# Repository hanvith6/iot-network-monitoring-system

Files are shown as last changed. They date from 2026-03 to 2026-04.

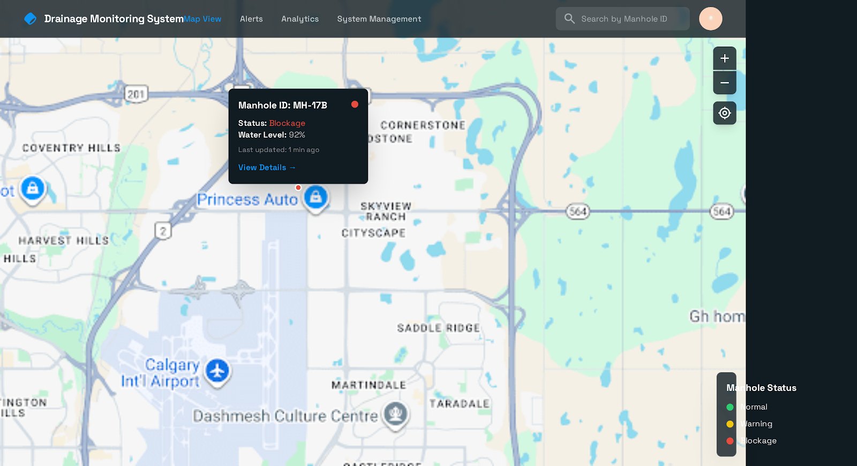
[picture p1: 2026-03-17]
docs/images/image copy 2.png

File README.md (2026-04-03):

# Real-Time Drainage Monitoring System

> **Final Year Project** — Real-time underground drainage monitoring using ESP32 microcontrollers, MQTT, ThingsBoard cloud, and a custom Next.js dashboard.

---

## Overview

This project implements an end-to-end IoT system for monitoring urban drainage infrastructure in real time. ESP32 edge nodes equipped with ultrasonic depth sensors and flow-rate meters continuously measure water levels inside drainage pipes. Readings are transmitted over WiFi via the MQTT protocol to a cloud broker, ingested by ThingsBoard for persistence and alerting, and visualised through a purpose-built web dashboard built with Next.js.

The system autonomously classifies pipe conditions across four severity levels — **Normal → Early Sedimentation → Partial Block → Overflow Risk** — and raises configurable alarms before a blockage becomes critical.

---

## System Architecture

```
┌─────────────────────────────────────────────────────────────┐
│                       EDGE LAYER                            │
│   ESP32 + HC-SR04 (Ultrasonic) + YF-S201 (Flow Sensor)     │
│   Multi-level state detection · Time-to-Overflow ETA        │
└──────────────────────────┬──────────────────────────────────┘
                           │ WiFi (802.11 b/g/n)
                           ▼
┌─────────────────────────────────────────────────────────────┐
│                     TRANSPORT LAYER                         │
│         MQTT Broker (Mosquitto / ThingsBoard MQTT)          │
│    Topic: v1/devices/me/telemetry  ·  Port 1883             │
└──────────────────────────┬──────────────────────────────────┘
                           │ JSON Telemetry Payload
                           ▼
┌─────────────────────────────────────────────────────────────┐
│                      CLOUD LAYER                            │
│    ThingsBoard (Device Management · Alarm Rules · API)      │
│    REST API / WebSocket for dashboard data feed             │
└──────────────────────────┬──────────────────────────────────┘
                           │ WebSocket / MQTT over WSS
                           ▼
┌─────────────────────────────────────────────────────────────┐
│                  VISUALISATION LAYER                        │
│     Next.js 16 Dashboard — Live charts, alarms, status      │
└─────────────────────────────────────────────────────────────┘
```

---

## Technologies Used

| Layer | Technology |
|---|---|
| Microcontroller | ESP32 (Espressif) |
| Sensors | HC-SR04 Ultrasonic, YF-S201 Flow Meter |
| Communication | MQTT (PubSubClient library) |
| MQTT Broker | Mosquitto (local) / ThingsBoard Cloud |
| Cloud Platform | ThingsBoard CE |
| Frontend | Next.js 16, React 19, Recharts, Tailwind CSS |
| Language | C++ (Firmware), TypeScript (Dashboard) |

---

## Repository Structure

```
iot-network-monitoring-system/
│
├── firmware/                         # ESP32 Arduino firmware
│   ├── esp32_firmware.ino            # Primary firmware (ThingsBoard MQTT)
│   ├── esp32_firmware_mosquitto.ino  # Variant for public Mosquitto broker
│   ├── esp32_firmware_blynk.ino      # Prototype variant (Blynk platform)
│   ├── PubSubClient.cpp              # MQTT client library
│   └── PubSubClient.h
│
├── dashboard/                        # Next.js web dashboard
│   ├── app/                          # App router pages
│   ├── components/                   # UI components
│   ├── hooks/use-system-data.ts      # MQTT data hook (live + simulation)
│   ├── lib/types.ts                  # Shared TypeScript types
│   └── package.json
│
├── thingsboard/
│   └── dashboards/                   # Exported ThingsBoard dashboard JSON files
│       ├── thingsboard_dashboard_final.json
│       ├── thingsboard_dashboard_v4.json
│       ├── thingsboard_dashboard_v2.json
│       └── thingsboard_dashboard.json
│
├── docs/                             # Project documentation
│   ├── architecture.md               # System design & data flow
│   ├── setup.md                      # Full setup & deployment guide
│   ├── alarm_setup.md                # ThingsBoard alarm configuration guide
│   └── images/                       # Architecture diagrams & screenshots
│
├── research/
│   └── IEEE_paper.docx               # Supporting IEEE research paper
│
├── .gitignore
└── README.md
```

---

## Documentation

### Guides

| Document | Description |
|---|---|
| [docs/setup.md](docs/setup.md) | **Full setup guide** — hardware wiring, firmware flashing, MQTT broker, ThingsBoard, and dashboard deployment |
| [docs/architecture.md](docs/architecture.md) | **System architecture** — layer-by-layer design, MQTT message flow, state machine, and data pipeline |
| [docs/alarm_setup.md](docs/alarm_setup.md) | **Alarm configuration** — step-by-step ThingsBoard Device Profile alarm rules |

### ThingsBoard Dashboards

All dashboard iterations are exported as importable JSON files in [`thingsboard/dashboards/`](thingsboard/dashboards/):

| File | Description |
|---|---|
| `thingsboard_dashboard_final.json` | **Latest production dashboard** (use this one) |
| `thingsboard_dashboard_v4.json` | Iteration 4 — refined layout |
| `thingsboard_dashboard_v2.json` | Iteration 2 — initial charts |
| `thingsboard_dashboard.json` | Original prototype |

### Research

> **IEEE paper currently under peer review — not yet published.**  
> The supporting research paper is available upon request. Contact via GitHub profile.  

---

## Key Features

- **Real-time telemetry** — flow rate (L/min), water level (cm), rise rate (cm/min), estimated time-to-overflow
- **Four-level state classification** — `NORMAL / EARLY_SEDIMENTATION / PARTIAL_BLOCK / OVERFLOW_RISK`
- **Edge intelligence** — state detection and ETA computation run entirely on the ESP32 (no cloud round-trip)
- **Alarm persistence** — 2-second hysteresis prevents flickering state transitions during turbulence
- **Dual-mode dashboard** — toggle between live MQTT data and simulated telemetry without code changes
- **Sound alerter** — browser audio notification on critical alarm
- **Battery monitoring** — LiPo voltage reported as percentage via ADC

---

## Quick Start

### Prerequisites

- Arduino IDE (≥ 2.0) with ESP32 board support
- Node.js 20+ and npm
- ThingsBoard account (cloud or self-hosted)

### 1 — Flash the ESP32

```bash
# Open in Arduino IDE
firmware/esp32_firmware.ino
```

Edit the configuration block at the top of the file:

```cpp
const char *ssid     = "YOUR_WIFI_SSID";
const char *password = "YOUR_WIFI_PASSWORD";
const char *mqtt_username = "YOUR_THINGSBOARD_ACCESS_TOKEN";
```

Upload to the ESP32 and open Serial Monitor (115200 baud) to confirm connection.

### 2 — Import the ThingsBoard Dashboard

1. Log in to your ThingsBoard instance.
2. Go to **Dashboards → Import Dashboard**.
3. Upload `thingsboard/dashboards/thingsboard_dashboard_final.json`.
4. Assign your device to the dashboard.

See [docs/alarm_setup.md](docs/alarm_setup.md) for configuring alarm rules.

### 3 — Run the Web Dashboard

```bash
cd dashboard
npm install
npm run dev
```

Open [http://localhost:3000](http://localhost:3000).  
Toggle **Live MQTT** in the UI to connect to `wss://test.mosquitto.org:8081` and receive real-time data. Use **Simulation** mode for offline testing.

Full step-by-step instructions are in [docs/setup.md](docs/setup.md).

---

## MQTT Payload Format

The ESP32 publishes JSON telemetry every 5 seconds:

```json
{
  "flow_lpm": 3.4,
  "water_level_cm": 28.5,
  "rise_rate_cm_per_min": 0.2,
  "overflow_eta_min": 85,
  "state": "EARLY_SEDIMENTATION",
  "alert_level": "WARNING",
  "battery_level": 87
}
```

---

## Alarm Levels

| State | Alert Level | Trigger Condition |
|---|---|---|
| `NORMAL` | NORMAL | Water level < 20 cm |
| `EARLY_SEDIMENTATION` | WARNING | Water level ≥ 20 cm |
| `PARTIAL_BLOCK` | ALERT | Water level ≥ 35 cm |
| `OVERFLOW_RISK` | CRITICAL | Water level ≥ 45 cm |

---

## License

This project is licensed under the [MIT License](LICENSE) — © 2026 Hanvith.

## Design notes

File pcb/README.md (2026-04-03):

# RTDMS PCB Design

Custom PCB for Real-Time Drainage Monitoring System.
ESP32-WROOM-32D-N4 + HC-SR04 + YF-S201 + SEN0189 + TDS Meter V1.0 + LCD1602A I2C

---

## Files

| File | Purpose |
|---|---|
| `generate_schematic.py` | Run to generate `rtdms.kicad_sch` |
| `rtdms.kicad_sch` | KiCad 7 schematic (generated) |
| `bom.csv` | Bill of materials with LCSC part numbers |

---

## Step 1 — Generate the Schematic

```bash
cd pcb
python generate_schematic.py          # generates rtdms.kicad_sch
python generate_schematic.py --check  # print netlist only
```

Requires Python 3.7+. No extra packages needed.

---

## Step 2 — Open in KiCad 7

1. Download KiCad 7 free from [kicad.org](https://www.kicad.org)
2. **File → Open Schematic** → select `rtdms.kicad_sch`
3. **Tools → Assign Footprints** — assign from `bom.csv` Footprint column
4. **File → Export → Netlist** → save as `rtdms.net`

---

## Step 3 — PCB Layout

1. Open **PCB Editor** (from KiCad main window)
2. **File → Import Netlist** → select `rtdms.net`
3. Board size: **80 × 60 mm**
4. Place components:
   - ESP32 headers (HDR_L, HDR_R) in centre
   - Screw terminals (J1–J4) on right edge — wires exit the side
   - LCD header (J5) on bottom edge
   - Power jack (J6) on left edge
   - Caps and resistors near ESP32
5. **Route → Interactive Router** (X key) — route all traces
   - Signal traces: 0.3 mm min width
   - Power traces (+5V / GND): 0.8 mm min width
6. Right-click empty area → **Add Copper Zone** → assign to GND → flood both layers
7. **Inspect → Design Rules Checker** — fix all errors

---

## Step 4 — Export Gerbers

1. **File → Fabrication Outputs → Gerbers**
2. Select all layers: F.Cu, B.Cu, F.SilkS, B.SilkS, F.Mask, B.Mask, Edge.Cuts
3. Also export **Drill Files** (Excellon format)
4. Zip all files → `rtdms_gerbers.zip`

---

## Step 5 — Order from JLCPCB

1. Go to [jlcpcb.com](https://jlcpcb.com)
2. **Upload Gerbers** → upload `rtdms_gerbers.zip`
3. Settings:
   - Layers: **2**
   - Dimensions: **80 × 60 mm**
   - PCB Qty: **5**
   - PCB Colour: **Blue** (standard)
   - Surface Finish: **HASL (with lead)** — cheapest
   - Copper Weight: **1 oz**
4. Cost: ~**$2 USD** + ~$8 shipping = ₹850 total
5. Production: 24–48 hrs → Shipping to India (DHL): 5–7 days

---

## Pin Map (from capstone.ino)

| Net | ESP32 GPIO | Connector |
|---|---|---|
| TRIG | GPIO5 | J1 pin 2 (HC-SR04) |
| ECHO | GPIO18 | J1 pin 3 (HC-SR04) |
| FLOW | GPIO19 | J2 pin 2 (YF-S201) |
| TURB_AO | GPIO34 | J3 pin 2 (SEN0189) |
| TDS_AO | GPIO32 | J4 pin 2 (TDS Meter) |
| SDA | GPIO23 | J5 pin 3 (LCD) + R2 pull-up |
| SCL | GPIO22 | J5 pin 4 (LCD) + R1 pull-up |
| +5V | VIN | J6 pin 1, all sensor VCC |
| GND | GND | J6 pin 2, all sensor GND |

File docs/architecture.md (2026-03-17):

# System Architecture

## Overview

The system is a four-layer IoT pipeline: edge sensing, MQTT transport, cloud processing, and web visualisation. Each layer has a single, well-defined responsibility, keeping the design modular and replaceable.

---

## Layer 1 — Edge (ESP32 Node)

### Hardware

| Component | Part | Role |
|---|---|---|
| Microcontroller | ESP32 WROOM-32 | Processing, WiFi, MQTT |
| Depth sensor | HC-SR04 Ultrasonic | Measures distance-to-water surface |
| Flow sensor | YF-S201 | Pulse-count based flow rate measurement |
| Power | LiPo battery (ADC monitored on GPIO 34) | Portable deployment |

### Firmware Logic

```
loop()
  ├── readWaterLevel()      — HC-SR04 pulse (TRIGGER GPIO5, ECHO GPIO18)
  ├── readFlowRate()        — Count pulses on GPIO27 over 5 s window
  ├── classifyState()       — Multi-level threshold comparison
  ├── estimateETA()         — Linear regression on rise rate
  ├── buildPayload()        — Serialize to JSON
  └── mqttPublish()         — Publish to broker topic
```

### State Classification Thresholds

```
Water Level (cm)    State                Alert Level
────────────────────────────────────────────────────
0  – 19.9           NORMAL               NORMAL
20 – 34.9           EARLY_SEDIMENTATION  WARNING
35 – 44.9           PARTIAL_BLOCK        ALERT
≥ 45                OVERFLOW_RISK        CRITICAL
```

### Hysteresis (Alert Persistence)

A 2-second stability timer (`PERSISTENCE_MS = 2000`) prevents the state from flickering when the water surface is turbulent. A state transition only commits if the new condition persists continuously for 2 seconds.

---

## Layer 2 — Transport (MQTT)

### Protocol

MQTT 3.1.1 over TCP (port 1883) or WebSocket (port 8081 for browser clients).

### Topics

| Direction | Topic | Used By |
|---|---|---|
| ESP32 → Broker | `v1/devices/me/telemetry` | ThingsBoard firmware variant |
| ESP32 → Broker | `drainage/data` | Mosquitto / dashboard variant |
| Browser → Broker | `drainage/data` (subscribe) | Next.js dashboard (WSS) |

### JSON Payload (published every ~5 s)

```json
{
  "flow_lpm":             3.4,
  "water_level_cm":       28.5,
  "rise_rate_cm_per_min": 0.2,
  "overflow_eta_min":     85,
  "state":                "EARLY_SEDIMENTATION",
  "alert_level":          "WARNING",
  "battery_level":        87
}
```

### Broker Options

| Broker | Use Case | Auth |
|---|---|---|
| `test.mosquitto.org:1883` | Development & demo | None |
| `mqtt.eu.thingsboard.cloud:1883` | Production (ThingsBoard) | Device Access Token |
| Local Mosquitto (`localhost:1883`) | Self-hosted / LAN | Configurable |

---

## Layer 3 — Cloud (ThingsBoard)

### Responsibilities

- **Device registry** — each ESP32 is registered as a Device with a unique Access Token.
- **Telemetry storage** — all JSON keys are stored as time-series data points.
- **Alarm engine** — Device Profile alarm rules fire when `state` or `alert_level` values match configured conditions (see [alarm_setup.md](alarm_setup.md)).
- **REST API / WebSocket** — exposes telemetry to external consumers (the web dashboard).

### Data Flow inside ThingsBoard

```
MQTT Ingest  →  Telemetry Store  →  Alarm Rule Evaluation
                                         ↓
                              Alarm Created / Cleared
                                         ↓
                              Dashboard Widgets notified
```

### Exported Dashboards

All dashboard configurations are exported as JSON and stored in `thingsboard/dashboards/`:

| File | Description |
|---|---|
| `thingsboard_dashboard_final.json` | Production dashboard (latest) |
| `thingsboard_dashboard_v4.json` | Iteration 4 — refined layout |
| `thingsboard_dashboard_v2.json` | Iteration 2 — initial charts |
| `thingsboard_dashboard.json` | Original prototype |

---

## Layer 4 — Visualisation (Next.js Dashboard)

### Stack

- **Next.js 16** (App Router) — server and client components
- **React 19** — UI state management
- **Recharts** — real-time line charts
- **Tailwind CSS v4** — styling
- **mqtt.js** — WebSocket MQTT client (runs in the browser)

### Component Map

```
app/(dashboard)/page.tsx
  ├── TopNavBar          — branding, navigation links
  ├── HeroSection        — project title & description
  ├── StatusCard ×4      — System Status, Alert Level, ETA, Rise Rate
  ├── RealTimeChart ×2   — Flow Rate, Water Level (sliding 30-point window)
  ├── AlarmLogTable      — timestamped alarm event history
  ├── BatteryIndicator   — live battery percentage
  └── SoundAlerter       — browser audio on CRITICAL alarm
```

### Data Hook — `useSystemData`

`hooks/use-system-data.ts` centralises all data concerns:

- **Live mode** — connects to `wss://test.mosquitto.org:8081`, subscribes to `drainage/data`, parses `ESP32Payload`, updates React state.
- **Simulation mode** — generates synthetic telemetry locally using a deterministic cycle to allow demonstration without hardware.
- Maintains a 30-sample rolling `history` array for chart rendering.
- Appends to `alarms` log whenever `alertLevel` escalates beyond NORMAL.

---

## End-to-End Data Flow

```
HC-SR04 / YF-S201 sensors (physical)
        ↓  GPIO interrupts / pulse timing
ESP32 ADC + Digital I/O
        ↓  state classification + ETA
JSON telemetry (MQTT PUBLISH)
        ↓  TCP / WiFi
MQTT Broker
        ↓  MQTT SUBSCRIBE
ThingsBoard  ←→  Alarm Engine
        ↓  WebSocket MQTT (wss://)
Browser (mqtt.js)
        ↓  React state update
Recharts / StatusCards / AlarmLogTable
        ↓
User sees live drainage telemetry
```

---

## Security Considerations

- Device credentials (WiFi SSID/password, ThingsBoard Access Token) are **not committed** to the repository. Template placeholder strings mark where real values must be inserted before flashing.
- Each ESP32 device authenticates to ThingsBoard using a unique per-device Access Token over MQTT.
- The public Mosquitto broker (`test.mosquitto.org`) is used for development only; production deployments should use a private broker with TLS.

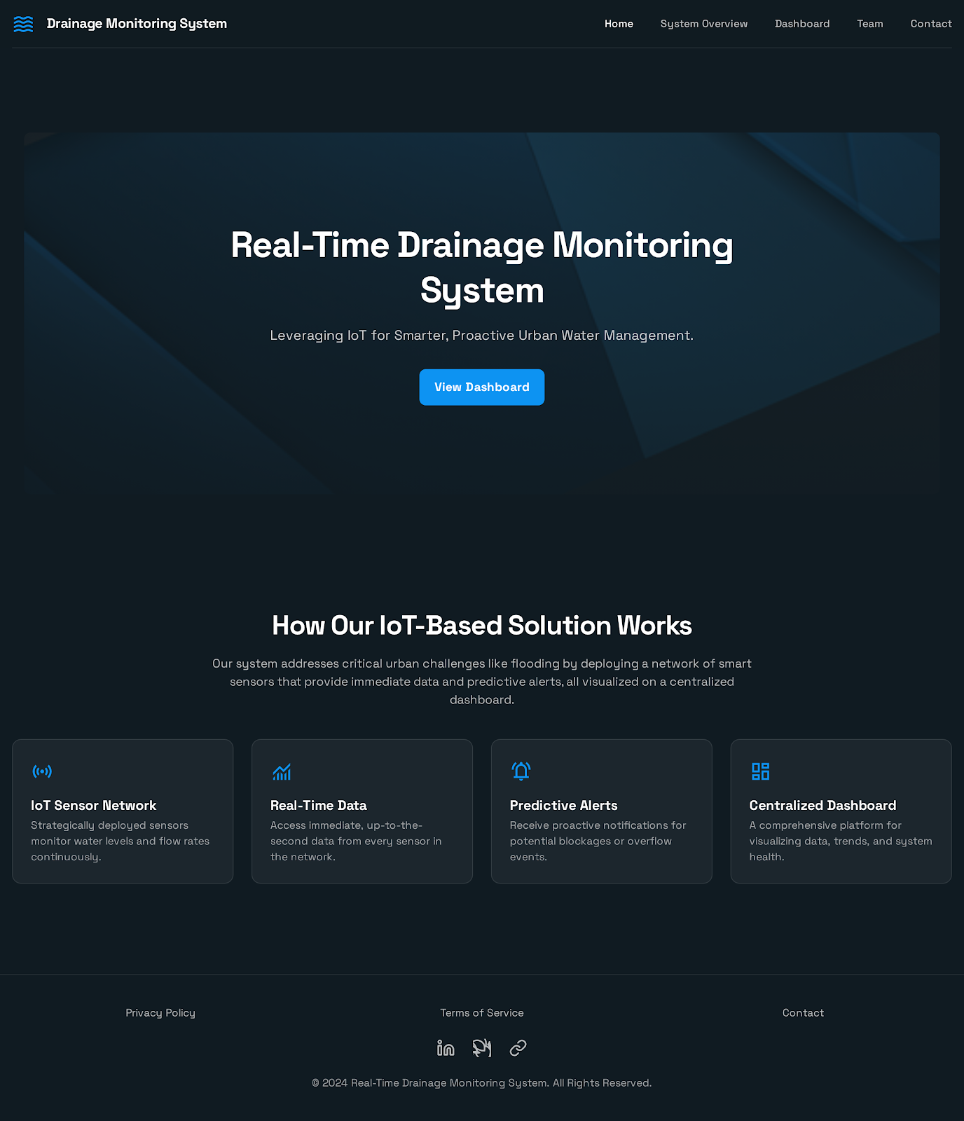
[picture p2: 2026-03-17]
docs/images/image.png

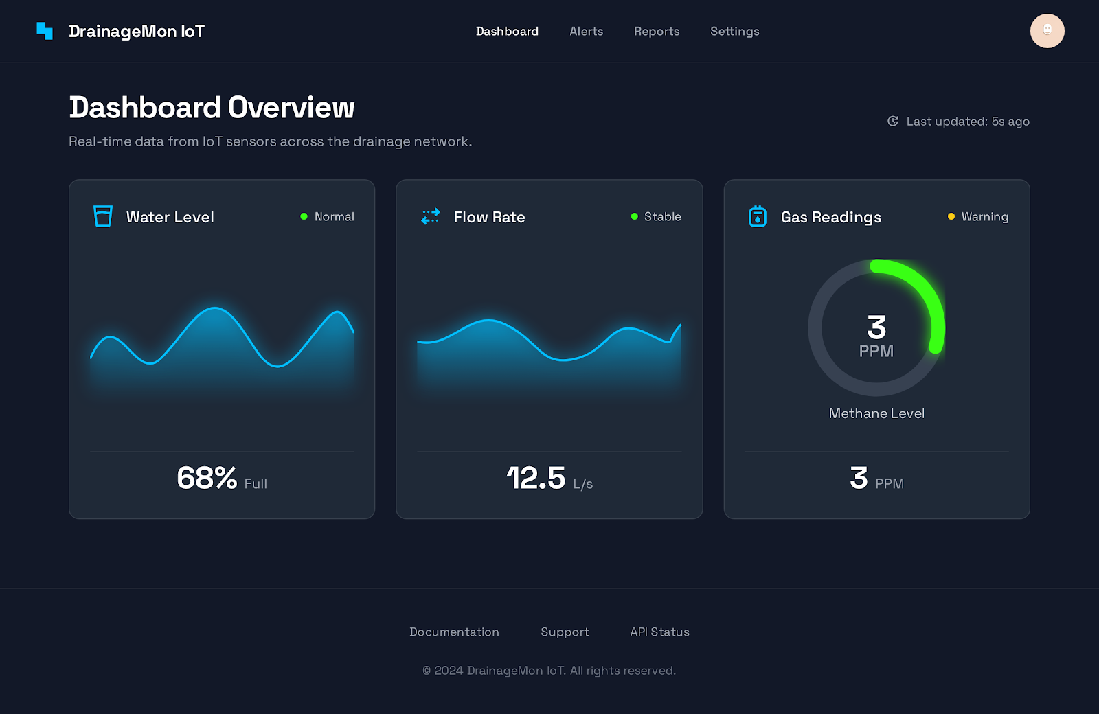
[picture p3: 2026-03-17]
docs/images/image copy.png

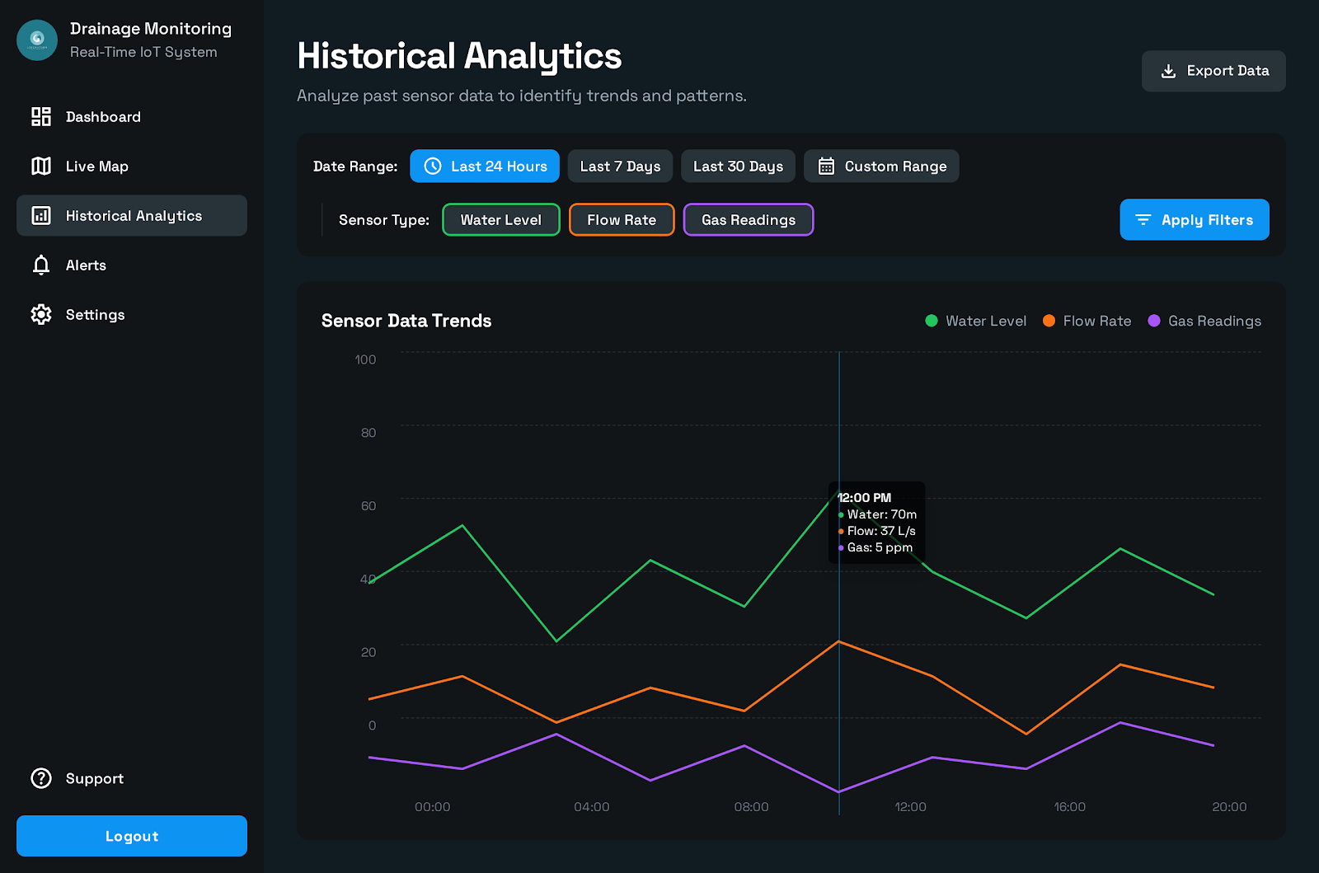
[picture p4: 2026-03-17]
docs/images/image copy 4.png

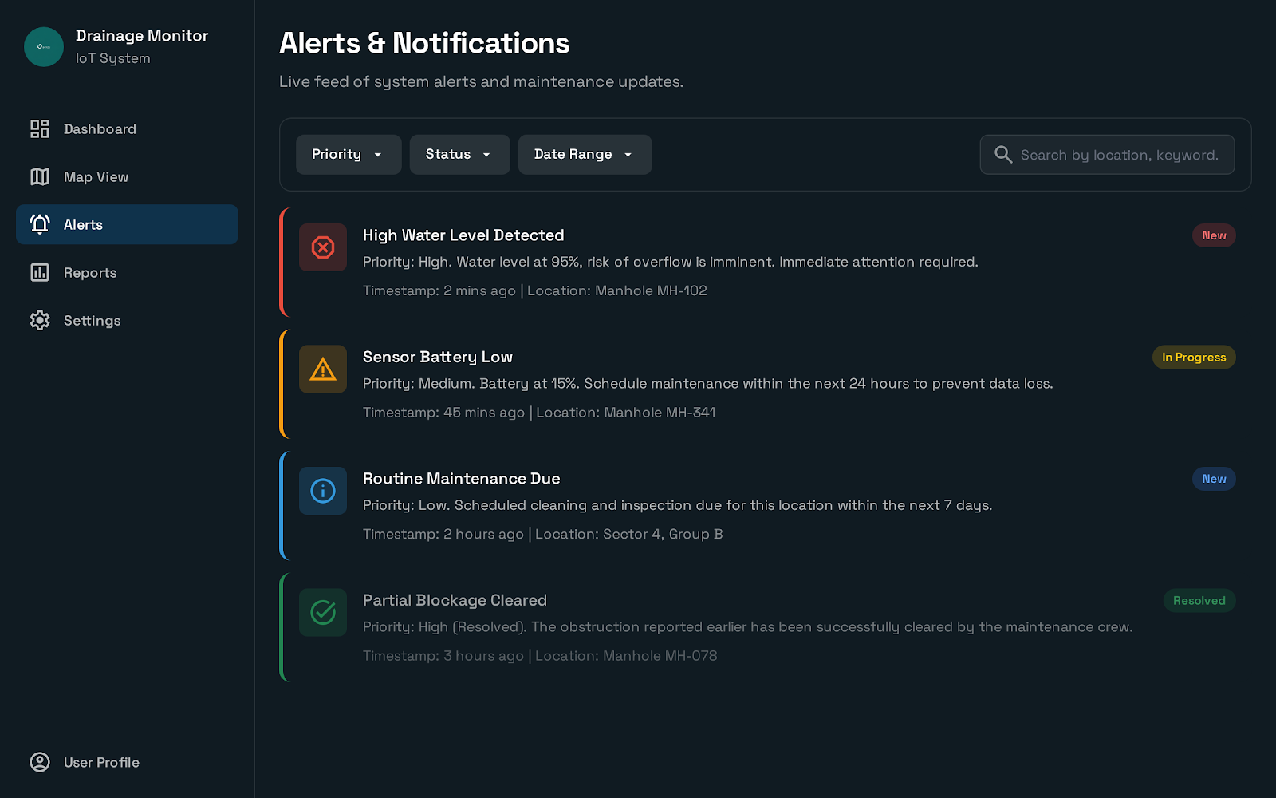
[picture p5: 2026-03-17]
docs/images/image copy 3.png

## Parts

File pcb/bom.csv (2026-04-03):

Ref | Qty | Value | Description | Footprint | LCSC Part | Buy From | Notes
U1 | 1 | ESP32-WROOM-32D-N4 | ESP32 WiFi/BT Module — DIRECT SOLDER castellated pads | RF_Module:ESP32-WROOM-32 | C701341 | JLCPCB / Robu.in | Solder directly to PCB pads — NOT on headers
U2 | 1 | AMS1117-3.3 | LDO Regulator 5V→3.3V 1A SOT-223 | Package_TO_SOT_SMD:SOT-223-3_TabPin2 | C6186 | JLCPCB / LCSC | Needed since no dev board regulator
J_PWR | 1 | DC-005 | 5.5mm barrel jack (5V input) | Connector_BarrelJack:BarrelJack_Horizontal | C136744 | JLCPCB | Power input from USB power bank
J_RAIL | 1 | PinHeader-1x12 | Power distribution strip 12-pin 2.54mm MALE | Connector_PinHeader_2.54mm:PinHeader_1x12_P2.54mm_Vertical | C429928 | JLCPCB / local | 6×VCC + 6×GND — sensors tap here with Dupont female
J1 | 1 | PinHeader-1x04 | HC-SR04 connector 4-pin 2.54mm MALE | Connector_PinHeader_2.54mm:PinHeader_1x04_P2.54mm_Vertical | C429926 | JLCPCB / local | Dupont female from sensor plugs here (VCC·TRIG·ECHO·GND)
J2 | 1 | PinHeader-1x03 | YF-S201 connector 3-pin 2.54mm MALE | Connector_PinHeader_2.54mm:PinHeader_1x03_P2.54mm_Vertical | C429925 | JLCPCB / local | VCC · SIG · GND
J3 | 1 | PinHeader-1x03 | SEN0189 turbidity connector 3-pin 2.54mm MALE | Connector_PinHeader_2.54mm:PinHeader_1x03_P2.54mm_Vertical | C429925 | JLCPCB / local | VCC · AO · GND
J4 | 1 | PinHeader-1x03 | TDS Meter V1.0 connector 3-pin 2.54mm MALE | Connector_PinHeader_2.54mm:PinHeader_1x03_P2.54mm_Vertical | C429925 | JLCPCB / local | VCC · AO · GND
J5 | 1 | PinHeader-1x04 | LCD 1602 I2C connector 4-pin 2.54mm MALE | Connector_PinHeader_2.54mm:PinHeader_1x04_P2.54mm_Vertical | C429926 | JLCPCB / local | GND · VCC · SDA · SCL
R_ECHO1 | 1 | 1kΩ 0805 | ECHO divider top — HC-SR04 5V→3.3V for GPIO18 | Resistor_SMD:R_0805_2012Metric | C17513 | JLCPCB | Works without on breadboard but correct for permanent PCB
R_ECHO2 | 1 | 2kΩ 0805 | ECHO divider bottom — mid-point ≈3.33V → GPIO18 | Resistor_SMD:R_0805_2012Metric | C17522 | JLCPCB | Protects GPIO18 from continuous 5V on soldered board
R_SCL | 1 | 4.7kΩ 0805 | I2C SCL pull-up → 3.3V | Resistor_SMD:R_0805_2012Metric | C17673 | JLCPCB | Required for I2C reliability
R_SDA | 1 | 4.7kΩ 0805 | I2C SDA pull-up → 3.3V | Resistor_SMD:R_0805_2012Metric | C17673 | JLCPCB | Required for I2C reliability
C1 | 1 | 100nF 0805 | 3.3V rail decoupling | Capacitor_SMD:C_0805_2012Metric | C49678 | JLCPCB | Place close to U1 VCC pin
C2 | 1 | 10µF 0805 | 3.3V rail bulk cap | Capacitor_SMD:C_0805_2012Metric | C440727 | JLCPCB | Place close to AMS1117 output
C3 | 1 | 100nF 0805 | 5V rail decoupling | Capacitor_SMD:C_0805_2012Metric | C49678 | JLCPCB | Place close to power input
C4 | 1 | 100µF SMD | 5V rail bulk cap | Capacitor_SMD:C_1210_3225Metric | C15008 | JLCPCB | Large bulk cap for sensor current spikes
H1-H4 | 4 | M3 3.2mm hole | PCB mounting holes | MountingHole:MountingHole_3.2mm_M3 | — | — | One at each corner

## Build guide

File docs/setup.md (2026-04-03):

# Setup & Deployment Guide

Complete instructions for deploying the Real-Time Drainage Monitoring System from scratch.

---

## Prerequisites

| Requirement | Version | Notes |
|---|---|---|
| Arduino IDE | ≥ 2.0 | With ESP32 board package installed |
| ESP32 board package | ≥ 2.0.0 | Install via Arduino Board Manager |
| Node.js | 20 LTS | For the Next.js dashboard |
| npm | ≥ 10 | Bundled with Node.js |
| ThingsBoard account | Any edition | [thingsboard.io](https://thingsboard.io) cloud or self-hosted |
| Mosquitto (optional) | ≥ 2.0 | Only needed for local broker variant |

---

## Hardware Wiring

| ESP32 GPIO | Component | Pin |
|---|---|---|
| GPIO 5 | HC-SR04 | TRIG |
| GPIO 18 | HC-SR04 | ECHO |
| GPIO 27 | YF-S201 Flow Sensor | Signal (interrupt) |
| GPIO 34 | LiPo battery (via voltage divider) | ADC (optional) |
| 3.3 V / GND | All sensors | Power |

> **Note:** The Mosquitto variant uses GPIO 19 instead of GPIO 27 for the flow sensor. Check the pin definitions at the top of each `.ino` file.

---

## Part 1 — ESP32 Firmware

### Step 1 — Install Arduino Libraries

In Arduino IDE go to **Sketch → Include Library → Manage Libraries** and install:

- `PubSubClient` by Nick O'Leary (or use the bundled `PubSubClient.cpp` / `PubSubClient.h` in `firmware/`)

For the Blynk variant only:

- `Blynk` by Volodymyr Shymanskyy

### Step 2 — Install ESP32 Board Support

1. Open **Arduino IDE → Preferences**.
2. Add to **Additional Board Manager URLs**:  
   `https://raw.githubusercontent.com/espressif/arduino-esp32/gh-pages/package_esp32_index.json`
3. Go to **Tools → Board → Board Manager**, search for `esp32`, and install.

### Step 3 — Configure Credentials

Open `firmware/esp32_firmware.ino` and fill in the configuration block near the top:

```cpp
// WiFi
const char *ssid     = "YOUR_WIFI_SSID";
const char *password = "YOUR_WIFI_PASSWORD";

// ThingsBoard MQTT
const char *mqtt_server   = "mqtt.eu.thingsboard.cloud";
const char *mqtt_username = "YOUR_THINGSBOARD_ACCESS_TOKEN";
const char *mqtt_password = "";   // leave blank for ThingsBoard
const int   mqtt_port     = 1883;
```

> **Security:** Never commit real credentials. Use the placeholder strings shown above in version control.

### Step 4 — Flash the Firmware

1. Connect ESP32 via USB.
2. Select **Tools → Board → ESP32 Dev Module** (or matching board).
3. Select the correct **Port**.
4. Click **Upload**.
5. Open **Serial Monitor** at **115200 baud** — you should see:

```
Connecting to YOUR_WIFI_SSID
.....
WiFi connected
Attempting MQTT connection...connected
```

### Firmware Variants

| File | Use Case |
|---|---|
| `esp32_firmware.ino` | **Primary** — ThingsBoard cloud, full state machine |
| `esp32_firmware_mosquitto.ino` | Mosquitto public/local broker, pairs with Next.js dashboard |
| `esp32_firmware_blynk.ino` | Prototype — Blynk mobile dashboard |

---

## Part 2 — MQTT Broker (Mosquitto Variant)

Skip this section if using ThingsBoard MQTT directly.

### Option A — Public Test Broker (Development Only)

No setup needed. The firmware connects to `test.mosquitto.org:1883`.  
The Next.js dashboard connects to `wss://test.mosquitto.org:8081`.

### Option B — Local Mosquitto Broker

```bash
# Install (macOS)
brew install mosquitto

# Start
brew services start mosquitto

# Test — subscribe in one terminal
mosquitto_sub -h localhost -t "drainage/data"

# Publish a test message
mosquitto_pub -h localhost -t "drainage/data" -m '{"flow_lpm":1.2,"water_level_cm":10,"state":"NORMAL","alert_level":"NORMAL","battery_level":95}'
```

Update `MQTT_BROKER` in `dashboard/hooks/use-system-data.ts` to point at your local broker:

```ts
const MQTT_BROKER = 'ws://localhost:9001';  // WebSocket port
```

---

## Part 3 — ThingsBoard Cloud Setup

### Step 1 — Create a Device

1. Log in at [thingsboard.cloud](https://thingsboard.cloud).
2. Go to **Entities → Devices → Add Device**.
3. Name it (e.g., `drainage-node-01`), leave profile as **default**.
4. Click **Manage Credentials** and copy the **Access Token** — paste it into the firmware as `mqtt_username`.

### Step 2 — Import the Dashboard

1. Go to **Dashboards → Import Dashboard**.
2. Upload `thingsboard/dashboards/thingsboard_dashboard_final.json`.
3. Open the dashboard and use **Entity Alias** settings to assign your device.

### Step 3 — Configure Alarm Rules

Follow the detailed guide in [docs/alarm_setup.md](alarm_setup.md).

Summary:
- Go to **Profiles → Device Profiles → default → Alarm Rules**.
- Add rule for `state == "OVERFLOW_RISK"` → Severity **CRITICAL**.
- Add rule for `state == "EARLY_SEDIMENTATION"` → Severity **WARNING**.
- Save the profile.

---

## Part 4 — Next.js Web Dashboard

### Step 1 — Install Dependencies

```bash
cd dashboard
npm install
```

### Step 2 — Run in Development Mode

```bash
npm run dev
```

Open [http://localhost:3000](http://localhost:3000).

### Step 3 — Choose Data Mode

The dashboard has two modes selectable from the UI:

| Mode | Description |
|---|---|
| **Simulation** | Generates synthetic telemetry locally — no hardware required |
| **Live MQTT** | Connects to `wss://test.mosquitto.org:8081`, topic `drainage/data` |

Toggle between modes using the button in the Live Telemetry control bar.

### Step 4 — Build for Production

```bash
npm run build
npm run start
```

Or deploy to [Vercel](https://vercel.com) by connecting the `dashboard/` folder as the project root.

---

## Verifying the Full Pipeline

Once all parts are running, you should be able to:

1. See ESP32 Serial Monitor print telemetry every ~5 seconds.
2. See messages arrive in `mosquitto_sub` or ThingsBoard **Latest Telemetry** tab.
3. See the Next.js dashboard update in real time with the correct values.
4. Trigger a `WARNING` alarm by holding the ultrasonic sensor closer than 30 cm (water level > 20 cm).

---

## Troubleshooting

| Symptom | Likely Cause | Fix |
|---|---|---|
| ESP32 stuck on `Connecting...` | Wrong SSID/password | Re-check credentials in firmware |
| `MQTT connection failed, rc=-2` | Broker unreachable | Check IP, port, and firewall |
| ThingsBoard shows no telemetry | Wrong Access Token | Re-copy token from Device Credentials |
| Dashboard shows "disconnected" | Test broker unreachable | Check internet; switch to Simulation mode |
| Water level reads `-1` | Ultrasonic out of range / no echo | Check wiring and sensor distance |

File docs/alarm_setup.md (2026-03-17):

# How to Create Alarms in ThingsBoard

The dashboard file handles the **widgets** (Charts, Cards), but **Alarms** must be created in the "Device Profile" section.

### Step 5: Create Alarm Rules (Manual Setup)

1.  **Go to Device Profiles**:
    *   In the Left Sidebar, click **Profiles** -> **Device Profiles**.
    *   Click on the **"default"** profile (or whichever profile your Device uses).

2.  **Open Alarm Rules**:
    *   Click the **Alarm rules** tab at the top.
    *   Click **Add alarm rule**.

### Alarm 1: Overflow Risk (Critical)
*   **Alarm Type**: `Overflow Risk`
*   **Create Alarm Condition**:
    *   Click **Add Key Filter**.
    *   Type: **Telemetry**.
    *   Key: `state`.
    *   Value Type: **String**.
    *   Operation: **Equal**.
    *   Value: `OVERFLOW_RISK` (Must match exact text from ESP32).
*   **Severity**: Select **CRITICAL** (Red).
*   Click **Add**.

### Alarm 2: Early Sedimentation (Warning)
*   **Alarm Type**: `Sedimentation Warning`
*   **Create Alarm Condition**:
    *   Click **Add Key Filter**.
    *   Type: **Telemetry**.
    *   Key: `state`.
    *   Value Type: **String**.
    *   Operation: **Equal**.
    *   Value: `EARLY_SEDIMENTATION`.
*   **Severity**: Select **WARNING** (Orange).
*   Click **Add**.

### Save Profile
*   Click the **Apply changes** (Checkmark) icon to save the profile.

**Verification:**
When your ESP32 detects blockages, a Red or Orange alarm bell will now appear on your new Dashboard!

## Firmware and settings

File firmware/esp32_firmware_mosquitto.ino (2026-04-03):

#include "PubSubClient.h"
#include <WiFi.h>

/*
 * EDGE PROCESSING NODE - REACT DASHBOARD VERSION
 * Broker: test.mosquitto.org (No Auth)
 * Topic: drainage/data
 */

// ------------------- CONFIGURATION ------------------- //
const char *ssid = "YOUR_WIFI_SSID";       // <-- Replace with your WiFi SSID
const char *password = "YOUR_WIFI_PASSWORD"; // <-- Replace with your WiFi password

// Mosquitto Broker (Public)
const char *mqtt_server = "test.mosquitto.org";
const int mqtt_port = 1883;
const char *mqtt_topic = "drainage/data";

// Pin Definitions
#define TRIGGER_PIN 5
#define ECHO_PIN 18
#define FLOW_PIN 19
#define BATTERY_PIN 34

// Constants
const float PIPE_DEPTH_CM = 50.0;
const float THRESHOLD_WARNING = 20.0;
const float THRESHOLD_ALERT = 35.0;
const float THRESHOLD_CRITICAL = 45.0;

WiFiClient espClient;
PubSubClient client(espClient);

// Globals
volatile int flow_pulse_count = 0;
float flow_rate_lpm = 0.0;
unsigned long last_time = 0;
float prev_water_level = 0.0;

void IRAM_ATTR pulseCounter() { flow_pulse_count++; }

void setup() {
  Serial.begin(115200);
  pinMode(TRIGGER_PIN, OUTPUT);
  pinMode(ECHO_PIN, INPUT);
  pinMode(FLOW_PIN, INPUT_PULLUP);
  pinMode(BATTERY_PIN, INPUT);
  attachInterrupt(digitalPinToInterrupt(FLOW_PIN), pulseCounter, FALLING);

  setup_wifi();
  client.setServer(mqtt_server, mqtt_port);
  prev_water_level = readWaterLevel();
}

void setup_wifi() {
  delay(10);
  Serial.print("Connecting to ");
  Serial.println(ssid);
  WiFi.begin(ssid, password);
  while (WiFi.status() != WL_CONNECTED) {
    delay(500);
    Serial.print(".");
  }
  Serial.println("\nWiFi connected");
}

void reconnect() {
  while (!client.connected()) {
    Serial.print("Attempting MQTT connection...");
    if (client.connect("ESP32Client-UniqueId")) {
      Serial.println("connected");
    } else {
      Serial.print("failed, rc=");
      Serial.print(client.state());
      delay(5000);
    }
  }
}

float readWaterLevel() {
  digitalWrite(TRIGGER_PIN, LOW);
  delayMicroseconds(2);
  digitalWrite(TRIGGER_PIN, HIGH);
  delayMicroseconds(10);
  digitalWrite(TRIGGER_PIN, LOW);
  long duration = pulseIn(ECHO_PIN, HIGH, 30000);
  if (duration == 0)
    return -1.0;
  float distance_cm = duration * 0.034 / 2;
  float level = PIPE_DEPTH_CM - distance_cm;
  return (level < 0) ? 0.0 : level;
}

int readBattery() {
  int raw = analogRead(BATTERY_PIN);
  // Assuming 2x voltage divider (100k/100k) and 3.3V reference
  // 3.3V = 4095
  // Voltage = (raw / 4095.0) * 3.3 * 2;
  // Map 3.3V (0%) to 4.2V (100%) roughly for LiPo
  // This is a rough estimation.
  float voltage =
      (raw / 4095.0) * 3.3 * 2; // Adjust multiplier based on actual divider
  int percentage = map((long)(voltage * 100), 300, 420, 0, 100);
  if (percentage < 0)
    percentage = 0;
  if (percentage > 100)
    percentage = 100;
  return percentage;
}

void calculateFlow(unsigned long elapsed_ms) {
  detachInterrupt(digitalPinToInterrupt(FLOW_PIN));
  float hz = (flow_pulse_count * 1000.0) / elapsed_ms;
  flow_rate_lpm = hz / 7.5;
  flow_pulse_count = 0;
  attachInterrupt(digitalPinToInterrupt(FLOW_PIN), pulseCounter, FALLING);
}

void loop() {
  if (!client.connected())
    reconnect();
  client.loop();

  unsigned long current_time = millis();
  unsigned long elapsed = current_time - last_time;

  if (elapsed >= 1000) {
    calculateFlow(elapsed);
    float water_level = readWaterLevel();
    if (water_level < 0)
      water_level = prev_water_level;

    int battery_level = readBattery();

    // Advanced Logic (Same as ThingsBoard version)
    float delta_level = water_level - prev_water_level;
    float elapsed_min = elapsed / 60000.0;
    if (elapsed_min == 0) elapsed_min = 0.001;
    float rise_rate = (delta_level / elapsed_min);
    if (abs(rise_rate) > 100)
      rise_rate = 0;

    float remaining_height = PIPE_DEPTH_CM - water_level;
    float eta_min = -1.0;
    if (rise_rate > 0.5 && remaining_height > 0) {
      eta_min = remaining_height / rise_rate;
    }

    String state = "NORMAL";
    if (water_level >= THRESHOLD_CRITICAL)
      state = "OVERFLOW_RISK";
    else if (water_level >= THRESHOLD_ALERT)
      state = "PARTIAL_BLOCK";
    else if (water_level >= THRESHOLD_WARNING && flow_rate_lpm < 2.0 && rise_rate > 0)
      state = "EARLY_SEDIMENTATION";

    // JSON Payload
    String payload = "{";
    payload += "\"flow_lpm\":";
    payload += String(flow_rate_lpm, 2);
    payload += ",";
    payload += "\"water_level_cm\":";
    payload += String(water_level, 2);
    payload += ",";
    payload += "\"rise_rate_cm_per_min\":";
    payload += String(rise_rate, 2);
    payload += ",";
    payload += "\"overflow_eta_min\":";
    payload += (eta_min < 0) ? "null" : String(eta_min, 1);
    payload += ",";
    payload += "\"state\":\"";
    payload += state;
    payload += "\",";
    String alert_level = "NORMAL";
    if (state == "OVERFLOW_RISK") alert_level = "CRITICAL";
    else if (state == "PARTIAL_BLOCK") alert_level = "ALERT";
    else if (state == "EARLY_SEDIMENTATION") alert_level = "WARNING";

    payload += "\"alert_level\":\"";
    payload += alert_level;
    payload += "\",";
    payload += "\"battery_level\":";
    payload += String(battery_level);
    payload += "}";

    Serial.println(payload);
    client.publish(mqtt_topic, payload.c_str());

    prev_water_level = water_level;
    last_time = current_time;
  }
}

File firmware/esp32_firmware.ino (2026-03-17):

#include "PubSubClient.h"
#include <WiFi.h>

/*
 * EDGE PROCESSING NODE - DRAINAGE MONITORING SYSTEM
 * Hardware: ESP32 + YF-S201 (Flow) + HC-SR04 (Ultrasonic)
 * Protocol: MQTT (ThingsBoard JSON Format)
 *
 * Logic Improvements:
 * - Multi-level state detection (Normal -> Critical) as per requirements.
 * - Time-to-Overflow (ETA) estimation based on rise rate.
 * - Alert persistence to prevent flickering states.
 * - Modular design for sensor reading and logic.
 */

// ------------------- CONFIGURATION ------------------- //
const char *ssid = "YOUR_WIFI_SSID";       // <-- Replace with your WiFi SSID
const char *password = "YOUR_WIFI_PASSWORD"; // <-- Replace with your WiFi password

// MQTT Broker Settings
// Option A: Public Test Broker (No Auth)
// const char *mqtt_server = "test.mosquitto.org";
// const char *mqtt_username = "";
// const char *mqtt_password = "";

// Option B: ThingsBoard (Demo or Local)
const char *mqtt_server =
    "mqtt.eu.thingsboard.cloud"; // Updated to specific host
const char *mqtt_username = "YOUR_THINGSBOARD_ACCESS_TOKEN"; // <-- Replace with your device access token
const char *mqtt_password = "";                                // Leave blank for ThingsBoard

const int mqtt_port = 1883;
const char *mqtt_topic =
    "v1/devices/me/telemetry"; // ThingsBoard Default Telemetry Topic

// Pin Definitions (PRESERVED)
#define TRIGGER_PIN 5 // Ultrasonic Trigger
#define ECHO_PIN 18   // Ultrasonic Echo
#define FLOW_PIN 27   // Flow Sensor (YF-S201)

// Pipe & Threshold Constants
const float PIPE_DEPTH_CM = 50.0; // Total depth of manhole/pipe
const float THRESHOLD_WARNING =
    20.0; // Water level cm for Warning (Early Sedimentation)
const float THRESHOLD_ALERT = 35.0;    // Water level cm for Partial Block
const float THRESHOLD_CRITICAL = 45.0; // Water level cm for Overflow Risk

// Safe Limits
const float MAX_VALID_DISTANCE = 400.0; // HC-SR04 Max range
const float MIN_VALID_DISTANCE = 2.0;

// ----------------------------------------------------- //

WiFiClient espClient;
PubSubClient client(espClient);

// Flow Sensor Globals
volatile int flow_pulse_count = 0;
float flow_rate_lpm = 0.0;
unsigned long last_time = 0;

// State Persistence Globals
String current_state = "NORMAL";
String current_alert = "NORMAL";
float prev_water_level = 0.0;
unsigned long persistence_timer = 0;
const int PERSISTENCE_MS = 2000; // State must be stable for 2s to change

// Interrupt Service Routine
void IRAM_ATTR pulseCounter() { flow_pulse_count++; }

void setup() {
  Serial.begin(115200);

  pinMode(TRIGGER_PIN, OUTPUT);
  pinMode(ECHO_PIN, INPUT);
  pinMode(FLOW_PIN, INPUT_PULLUP);
  attachInterrupt(digitalPinToInterrupt(FLOW_PIN), pulseCounter, FALLING);

  setup_wifi();
  client.setServer(mqtt_server, mqtt_port);

  // Initial reading to stabilize prev_water_level
  prev_water_level = readWaterLevel();
}

void setup_wifi() {
  delay(10);
  Serial.print("Connecting to ");
  Serial.println(ssid);
  WiFi.begin(ssid, password);
  while (WiFi.status() != WL_CONNECTED) {
    delay(500);
    Serial.print(".");
  }
  Serial.println("\nWiFi connected");
}

void reconnect() {
  while (!client.connected()) {
    Serial.print("Attempting MQTT connection...");
    String clientId = "ESP32-DrainageNode-" + String(random(0xffff), HEX);

    // THINGSBOARD AUTHENTICATION: Use Token as Username
    if (client.connect(clientId.c_str(), mqtt_username, mqtt_password)) {
      Serial.println("connected");
    } else {
      Serial.print("failed, rc=");
      Serial.print(client.state());
      Serial.println(" try again in 5 seconds");
      delay(5000);
    }
  }
}

// Modular Sensor Functions
float readWaterLevel() {
  digitalWrite(TRIGGER_PIN, LOW);
  delayMicroseconds(2);
  digitalWrite(TRIGGER_PIN, HIGH);
  delayMicroseconds(10);
  digitalWrite(TRIGGER_PIN, LOW);

  long duration = pulseIn(ECHO_PIN, HIGH, 30000); // 30ms timeout
  if (duration == 0)
    return -1.0; // Error or out of range

  float distance_cm = duration * 0.034 / 2;

  // Sanity Checks
  if (distance_cm > MAX_VALID_DISTANCE || distance_cm < MIN_VALID_DISTANCE)
    return -1.0;

  // Convert distance from top (air gap) to water level (fill)
  float level = PIPE_DEPTH_CM - distance_cm;
  return (level < 0) ? 0.0 : level;
}

void calculateFlow(unsigned long elapsed_ms) {
  detachInterrupt(digitalPinToInterrupt(FLOW_PIN));
  // YF-S201 Formula: F(Hz) = 7.5 * Q(L/min)
  // Q = Hz / 7.5
  float hz = (flow_pulse_count * 1000.0) / elapsed_ms;
  flow_rate_lpm = hz / 7.5;
  flow_pulse_count = 0;
  attachInterrupt(digitalPinToInterrupt(FLOW_PIN), pulseCounter, FALLING);
}

void loop() {
  if (!client.connected())
    reconnect();
  client.loop();

  unsigned long current_time = millis();
  unsigned long elapsed = current_time - last_time;

  if (elapsed >= 1000) { // Update every 1 second
    calculateFlow(elapsed);

    // 1. Get Sensor Data
    float water_level = readWaterLevel();
    if (water_level < 0)
      water_level = prev_water_level; // Hold last valid if error

    // 2. Calculate Rise Rate (cm/min)
    // dL/dt = (Current - Prior) / (elapsed_seconds / 60)
    float delta_level = water_level - prev_water_level;
    float elapsed_min = elapsed / 60000.0;
    float rise_rate = (delta_level / elapsed_min); // cm per minute

    // Smoothing for Display (Simple Low Pass)
    if (abs(rise_rate) > 100)
      rise_rate = 0; // Filter noise spikes

    // 3. Estimate Time to Overflow (minutes)
    // Logic: Remaining Height / Rise Rate
    float remaining_height = PIPE_DEPTH_CM - water_level;
    float eta_min = -1.0; // -1 indicates "Stable/No Risk"

    if (rise_rate > 0.5 &&
        remaining_height > 0) { // Only calculate if rising > 0.5cm/min
      eta_min = remaining_height / rise_rate;
    }

    // 4. Edge Logic & State Management
    String new_state = "NORMAL";
    String new_alert_level = "NORMAL";

    if (water_level >= THRESHOLD_CRITICAL) {
      new_state = "OVERFLOW_RISK";
      new_alert_level = "CRITICAL";
    } else if (water_level >= THRESHOLD_ALERT) {
      new_state = "PARTIAL_BLOCK";
      new_alert_level = "ALERT";
    } else if (water_level >= THRESHOLD_WARNING) {
      if (flow_rate_lpm < 2.0 && rise_rate > 0) {
        new_state = "EARLY_SEDIMENTATION"; // Rising slowly, low flow
        new_alert_level = "WARNING";
      } else {
        new_state = "NORMAL"; // Just high water, but flowing okay
        new_alert_level = "NORMAL";
      }
    }

    // 5. Alert Persistence (Debounce)
    if (new_state != current_state) {
      if ((millis() - persistence_timer) > PERSISTENCE_MS) {
        current_state = new_state;
        current_alert = new_alert_level;
        persistence_timer = millis();
      }
    } else {
      persistence_timer = millis(); // Reset timer if stable
    }
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

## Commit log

2026-03-29 Switch to compatibility-safe simple-card dashboard profile
2026-03-29 Bind dashboard datasource to single device ID to prevent unresolved loading
2026-03-29 Switch automation to v4 template-driven ThingsBoard layout and normalize widget config
2026-04-03 feat: RTDMS v2 — multi-sensor firmware, dashboard overhaul, bug fixes
    Firmware (esp32_firmware_mosquitto.ino):
    - Fix alert_level: now emits CRITICAL/ALERT/WARNING/NORMAL correctly (was NORMAL/ALERT only)
    - Fix EARLY_SEDIMENTATION: add missing rise_rate > 0 guard
    - Fix elapsed_min division-by-zero guard
    Dashboard:
    - Add turbidity (SEN0189), TDS, fill_percent, flowIndex fields to types + hook
    - Live MQTT now targets ThingsBoard (wss://mqtt.eu.thingsboard.cloud:8883)
    - Simulation updated: correct 45cm pipe depth, BDA flow index, turbidity/TDS simulation
    - Fix AlarmLogTable filter (was matching state names instead of severity)
    - Fix StatusCard: replace(/_/g, ' ') — was only replacing first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
    [esp32_firmware_mosquitto.ino]
2026-04-03 feat: add PCB design files for RTDMS custom board
    - pcb/generate_schematic.py — Python generator, outputs rtdms.kicad_sch
    - pcb/rtdms.kicad_sch — KiCad 7 schematic (all 5 sensors + ESP32 headers)
    - pcb/bom.csv — BOM with LCSC part numbers for JLCPCB assembly
    - pcb/README.md — step-by-step: KiCad → route → Gerber → JLCPCB order
    Netlist covers: HC-SR04, YF-S201, SEN0189, TDS Meter V1.0,
    LCD1602A I2C, barrel jack, decoupling caps, I2C pull-ups.
    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
    [bom.csv, rtdms.kicad_sch]
2026-04-03 feat(pcb): v2 — direct-solder ESP32, Dupont headers, power rail
    - ESP32-WROOM-32D soldered directly (castellated pads, RF_Module footprint)
    - AMS1117-3.3 LDO on-board (no dev-board regulator needed)
    - All sensor connectors: 2.54mm male headers (Dupont female plugs in)
    - 12-pin power rail strip: 6×VCC + 6×GND on PCB edge
    - HC-SR04 ECHO voltage divider 1kΩ/2kΩ: 5V→3.3V protects GPIO18
    - I2C pull-ups 4.7kΩ each on SDA/SCL
    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
    [bom.csv, rtdms_v2.kicad_sch]
2026-04-03 fix(pcb): restore ECHO voltage divider — correct for permanent PCB
    HC-SR04 ECHO (5V) → 1kΩ/2kΩ divider → 3.3V → GPIO18.
    Works without divider on breadboard (ESP32 ESD clamps handle it)
    but divider is correct engineering for a soldered PCB where GPIO18
    sees continuous 5V. 2 cheap 0805 resistors, no extra wiring needed.
    [bom.csv, rtdms_v2.kicad_sch]
